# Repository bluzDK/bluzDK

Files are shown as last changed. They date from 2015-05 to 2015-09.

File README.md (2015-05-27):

<p align="center" >
GoGlove
</p>

Bluz DK Hardware Files
==========
Bluz is a Development Kit (DK) that implements the Wiring language and talks to the [Particle](https://www.particle.io/) cloud through Bluetooth Low Energy. It can be accessed through a REST API and programmed from a Web IDE.

These files have been made available online through a [Creative Commons Attribution-ShareAlike 3.0](http://creativecommons.org/licenses/by-sa/3.0/) license.

You are welcome to distribute, remix, and use these files for commercial purposes. If you do so, please attribute the original design to Bluz both on the website and on the physical packaging of the product or in the instruction manual. All derivative works must be published under the same or a similar license.

All items are subject to change over time as the product is designed, so make sure you are always looking at the latest information by pulling often.

##Sections
<b>BOM</b>: Current Bill of Materials for bluz.

<b>Datasheets</b>: Datasheets for all major parts on the board, including the nrf51822 and the MDBT40 module that it uses.

<b>HW Design</b>: Schematics, board layouts, and other design files.

<b>HW Libraries</b>: Eagle CAD libraries for the components used on Bluz DK.

<b>Pin Mapping</b>: Pin mapping diagram for Bluz.

##Tech Specs
<p>Hardware</p>
<ul>
    <li>Nordic Semiconductor nRF51822 SoC</li>
    <li>ARM Cortex M0, 16MHz</li>
    <li>32KB RAM, 256KB FLASH</li>
    <li>Bluetooth LE 4.1</li>
    <li>10 bit ADC</li>
    <li>256KB External FLASH</li>
    <li>3.0V-6V (3.3V compatible)</li>
</ul>
<p>Power Consumption</p>
<ul>
    <li>Connected/Standby: 60uA</li>
    <li>Transmitting Max: 18mA</li>
</ul>
<p>Typical Range (subject to environment):</p>
<ul>
    <li>Indoors: 60-100 feet</li>
    <li>Outdoors: 150-200 feet</li>
</ul>
<p>Software</p>
<ul>
    <li>Spark Web IDE</li>
    <li>Wiring (same as Arduino)</li>
    <li>Native C/C++ Programming</li>
    <li>GCC ARM</li>
    <li>Assembly (if you're that bold)</li>
</ul>
<p>Cloud</p>
<ul>
    <li>Spark Connected</li>
    <li>IFTTT Integrated</li>
    <li>IPv6 Support</li>
    <li>Remote programmable through Spark Cloud</li>
    <li>Control via REST API</li>
</ul>

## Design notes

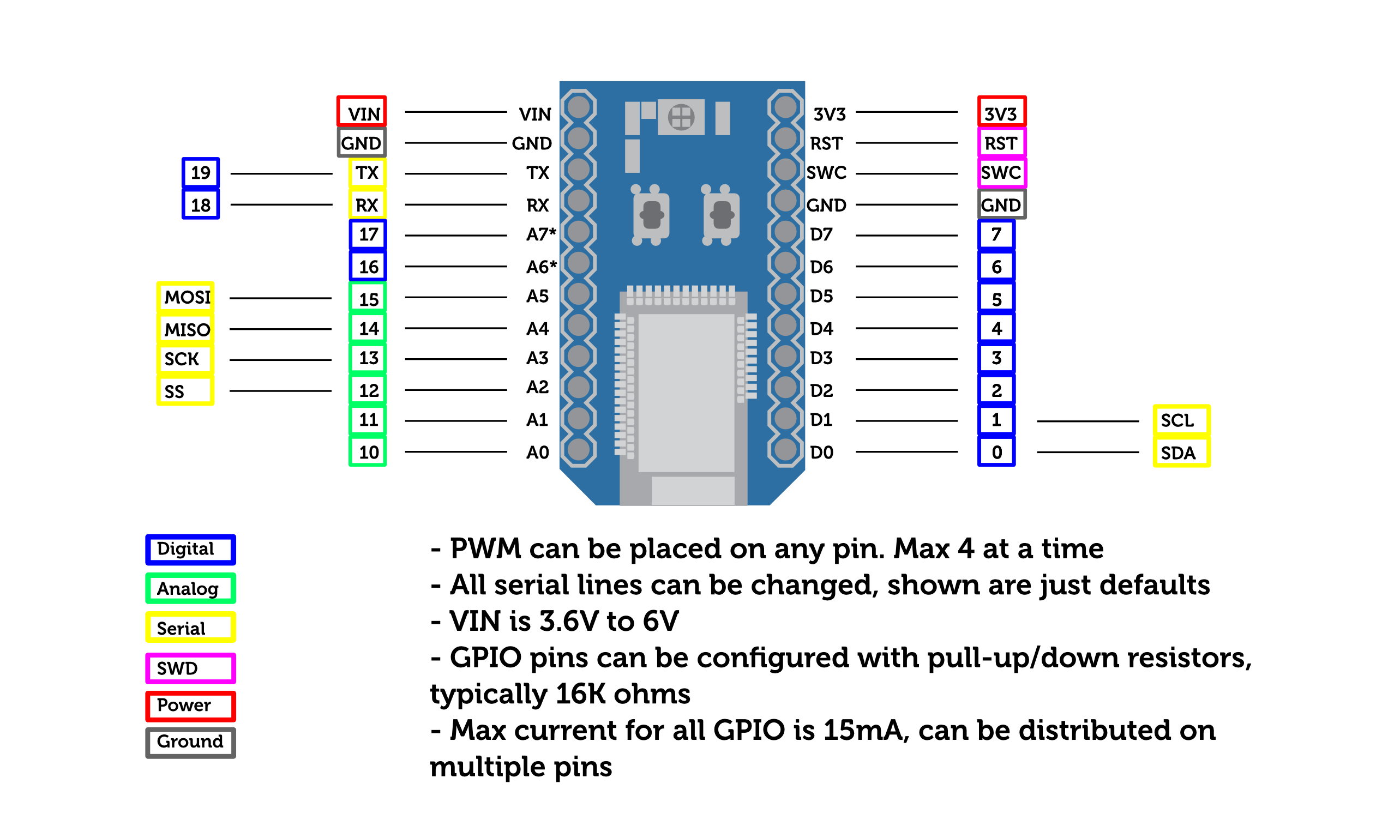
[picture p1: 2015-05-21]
v2/PinMapping/bluz_pinout.png

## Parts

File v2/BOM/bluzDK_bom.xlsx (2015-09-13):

Part(s) | Package | Value | Description | Qty | Manufacturer | Mfg. Part Number | Data Sheet | Notes
U1 | SMD |  | nrf51822 module with 32K RAM | 1 | Raytac | MDBT40-256R | data (http://www.raytac.com/download/MDBT40/MDBT40%20spec-Version%20A2.pdf)
U2 | SOIC-8 | 2Mb | 2Mb SPI Flash | 1 | Microcip | SST25VF020B-80-4I-SAE | data (http://ww1.microchip.com/downloads/en/DeviceDoc/20005054C.pdf)
U3 | SOT-23-3 |  | Linear regulator with 3.3V output, 3.7V-6.0V Input | 1 | Microchip | MCP1700T-3302E/TT | data (http://ww1.microchip.com/downloads/en/DeviceDoc/20001826C.pdf)
Q1 |  | 32.768KHz | 20ppm, 9pF, 32.768KHz crystal | 1 |  | ABS06-32.768KHZ-9-T | data (http://www.abracon.com/Resonators/ABS06.pdf)
C1-C3 | 0603 | 1uF | 0603 Package | 1 |  | CL10B105KP8NNNC | data (http://www.samsungsem.com/kr/front/downloadcms.do?fileName=S_CL10B105KP8NNNC.pdf)
C4, C5 | 0603 | 0.1uF | 0603 Package | 3 |  | GRM188R71C104KA01D | data (http://search.murata.co.jp/Ceramy/image/img/A01X/partnumbering_e_01.pdf)
C6, C7 | 0603 | 12pF | 0603 Package | 2 |  | CL10C120JB8NNNC | data (http://www.samsungsem.com/kr/front/downloadcms.do?fileName=S_CL10C120JB8NNNC.pdf)
R1-R3 | 0603 | 4.7k Ohm | 4.7k Ohm | 3 |  | CRCW06034K70JNEA | data (http://www.vishay.com/docs/20035/dcrcwe3.pdf)
R4-R5 | 0603 | 1k Ohm | 1k Ohm | 2 |  | CRCW06031K00FKEA | data (http://www.vishay.com/docs/20035/dcrcwe3.pdf)
R6 | 0603 | 10k Ohm | 10k Ohm | 1 |  | CRCW060310K0FKEA | data (http://www.vishay.com/docs/20035/dcrcwe3.pdf)
S1, S1 | SMD |  | 3.5mmx2.9mm Tactile Switch | 2 |  | EVP-AA202K | data (http://industrial.panasonic.com/www-data/pdf/ATK0000/ATK0000CE26.pdf)
L1 | SMD |  | 3.2mm x 2.7m RGB LED | 1 |  | CLVBA-FKA-CAEDH8BBB7A363 | data (http://www.cree.com/~/media/Files/Cree/LED%20Components%20and%20Modules/HB/Data%20Sheets/CLVBAFKA.pdf)
L2 | 0603 |  | White SMD LED | 1 |  | LW Q38G-Q1S1-3K6L-1 | data (http://www.osram-os.com/Graphics/XPic6/00086183_0.pdf)
JP1, JP2 | Thru |  | 0.1" 12-pin header | 2 |  | 68000-412HLF | data (http://www.digikey.com/product-detail/en/68000-412HLF/609-3266-ND/1878525)

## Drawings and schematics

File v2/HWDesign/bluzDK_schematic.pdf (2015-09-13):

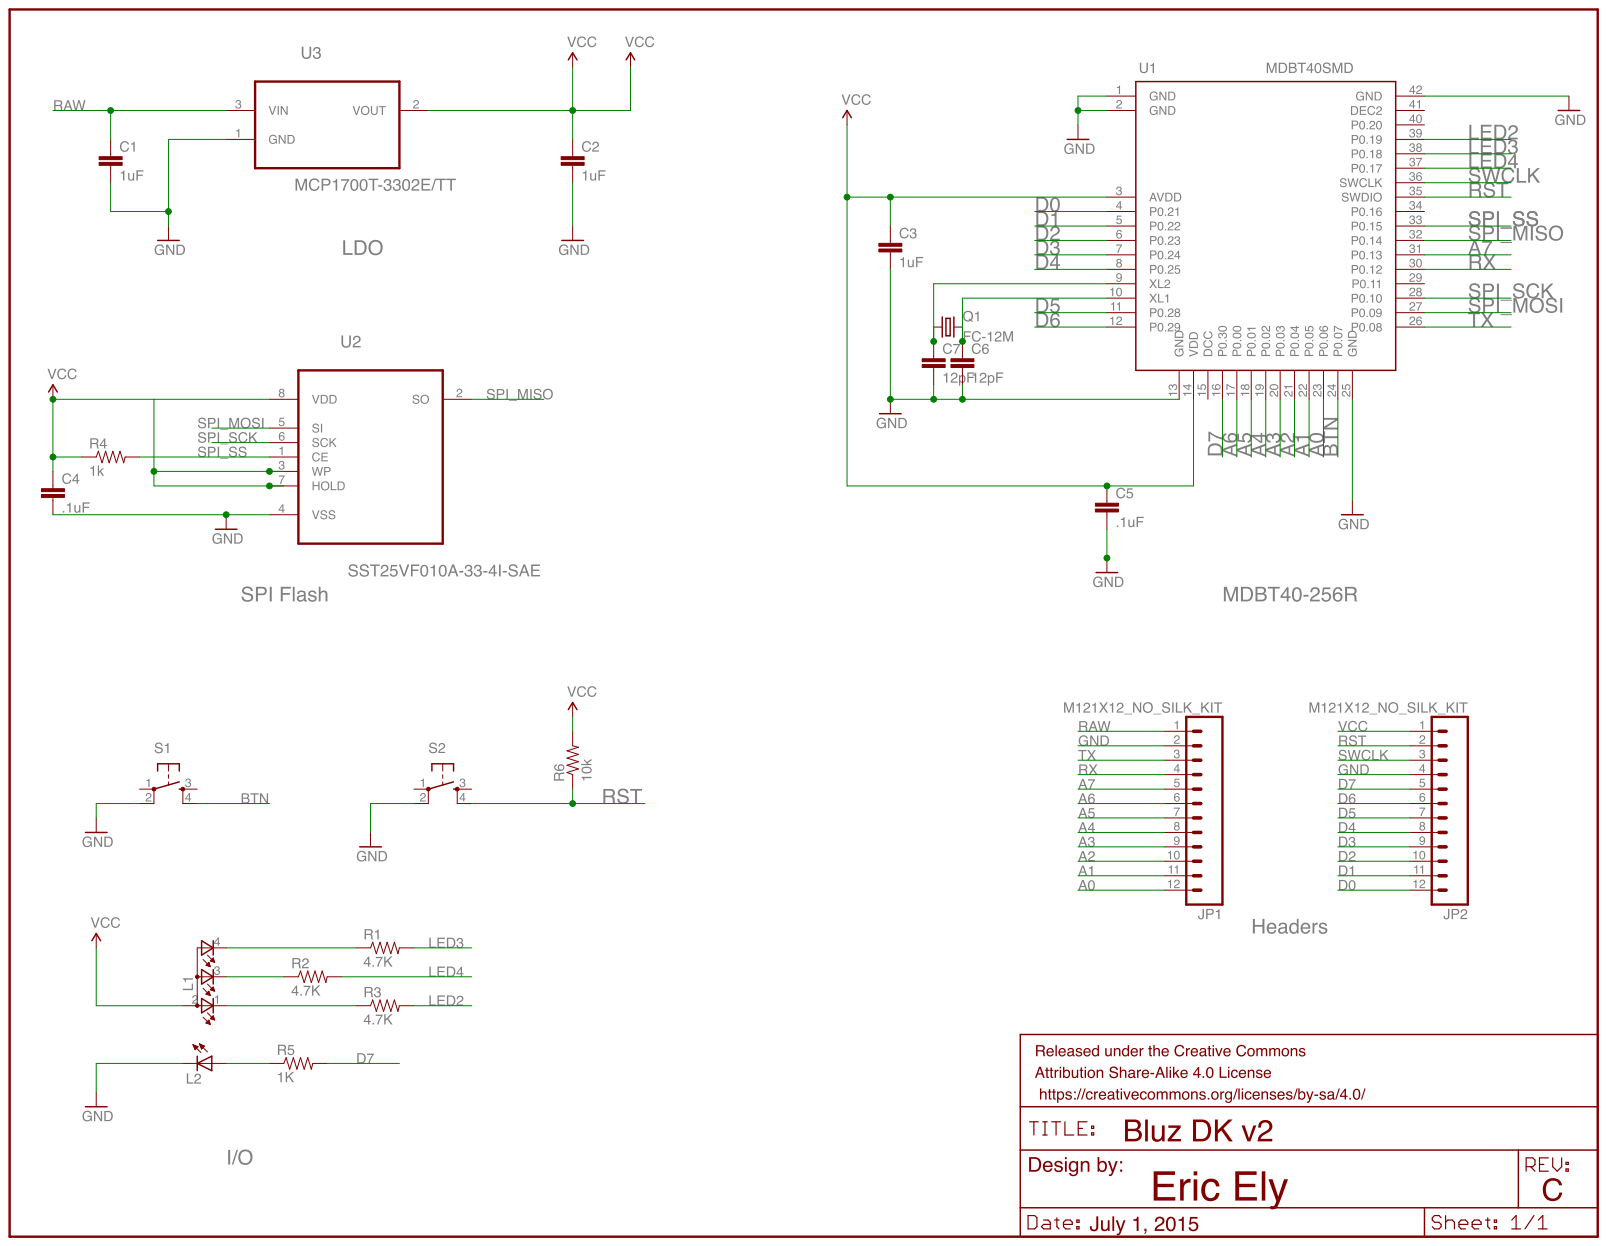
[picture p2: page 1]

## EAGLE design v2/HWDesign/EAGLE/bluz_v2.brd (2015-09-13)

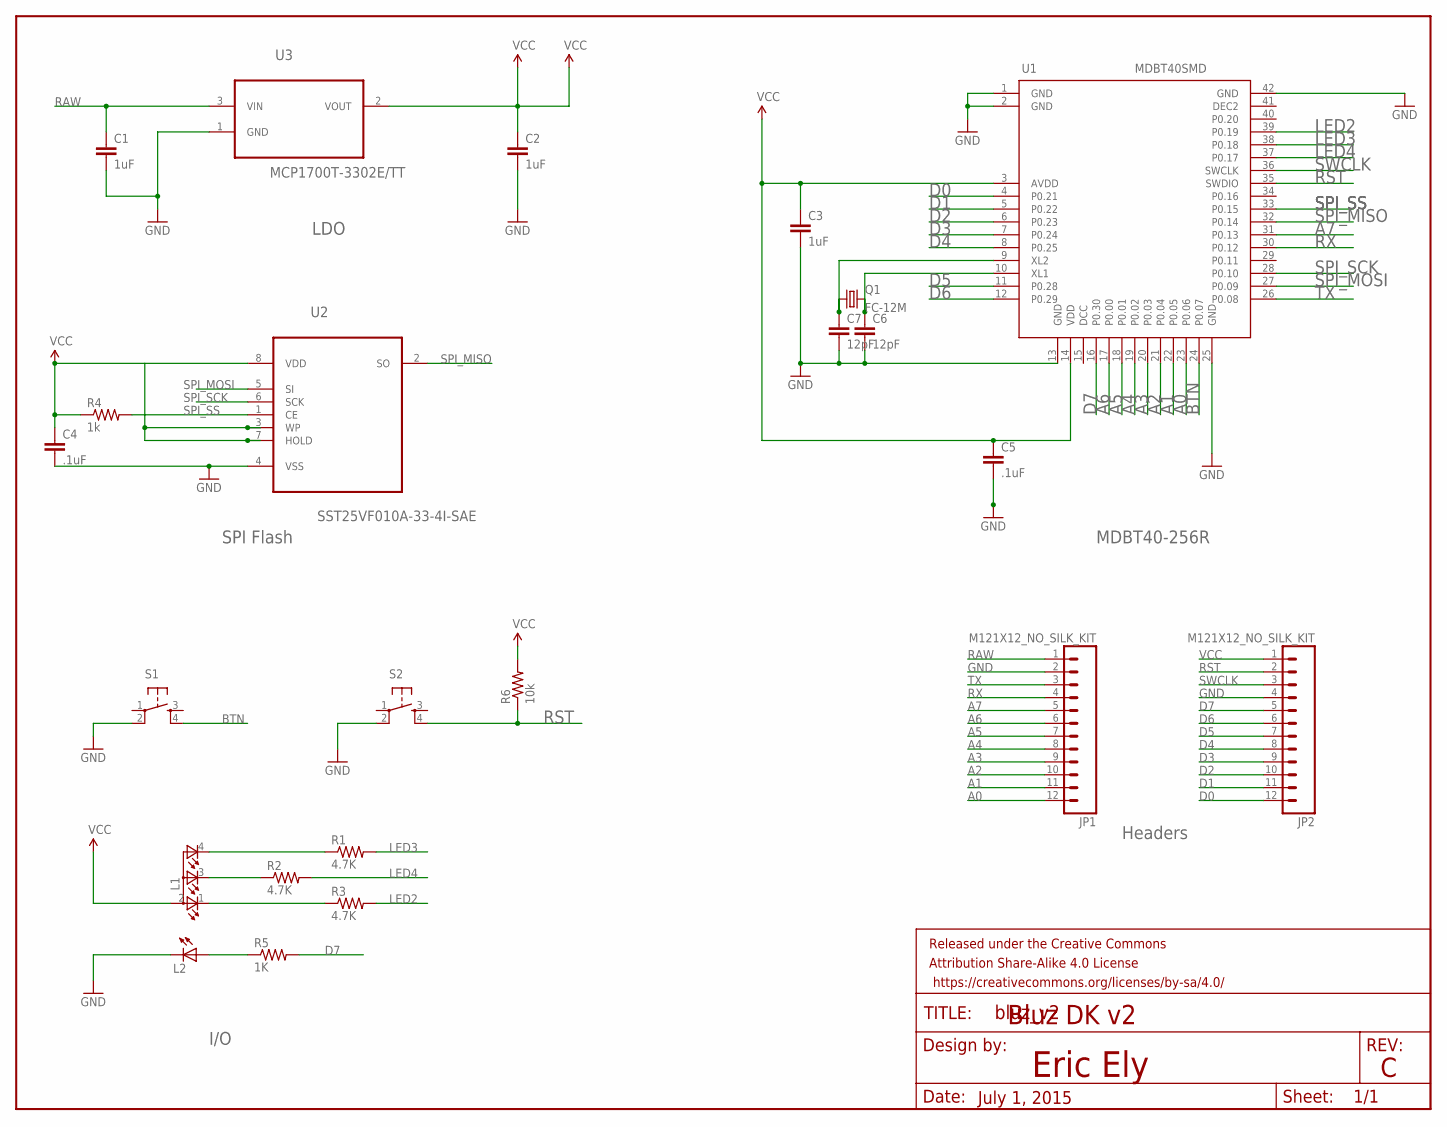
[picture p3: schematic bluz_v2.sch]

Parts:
C1, C2, C3: 1uF; 0603-CAP
C4, C5: .1uF; 0603-CAP
C6, C7: 12pF; 0603-CAP
FRAME1: FRAME-LETTER; CREATIVE_COMMONS
JP1, JP2: M121X12_NO_SILK_KIT; 1X12_NO_SILK_KIT
L1: TOPLED-3PLCC; P-LCC-4-3
L2: LEDCHIP-LED0603; CHIP-LED0603
Q1: FC-12M
R1, R2, R3: 4.7K; 0603-RES
R4: 1k; 0603-RES
R5: 1K; 0603-RES
R6: 10k; 0603-RES
S1, S2: TAC_SWITCHSMD; TACTILE_SWITCH_SMD
U1: MDBT40SMD; MDBT40
U2: SST25VF010A-33-4I-SAE; SOIC127P600X175-8N
U3: MCP1700T-3302E/TT; SOT95P237X112-3N

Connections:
A0: JP1.12, U1.23 (P0.06)
A1: JP1.11, U1.22 (P0.05)
A2: JP1.10, U1.21 (P0.04)
A3: JP1.9, U1.20 (P0.03)
A4: JP1.8, U1.19 (P0.02)
A5: JP1.7, U1.18 (P0.01)
A6: JP1.6, U1.17 (P0.00)
A7: JP1.5, U1.31 (P0.13)
BTN: S1.4, U1.24 (P0.07)
D0: JP2.12, U1.4 (P0.21)
D1: JP2.11, U1.5 (P0.22)
D2: JP2.10, U1.6 (P0.23)
D3: JP2.9, U1.7 (P0.24)
D4: JP2.8, U1.8 (P0.25)
D5: JP2.7, U1.11 (P0.28)
D6: JP2.6, U1.12 (P0.29)
D7: JP2.5, R5.2, U1.16 (P0.30)
GND: C1.2, C2.2, C3.2, C4.2, C5.2, C6.2, C7.2, JP1.2, JP2.4, L2.C, S1.2, S2.2, U1.1 (GND), U1.2 (GND), U1.13 (GND), U1.25 (GND), U1.42 (GND), U2.4 (VSS), U3.1 (GND)
LED2: R3.2, U1.39 (P0.19)
LED3: R1.2, U1.38 (P0.18)
LED4: R2.2, U1.37 (P0.17)
unnamed: C7.1, Q1.1, U1.9 (XL2)
unnamed: C6.1, Q1.2, U1.10 (XL1)
unnamed: L2.A, R5.1
unnamed: L1.1 (CRED), R3.1
unnamed: L1.3 (CBLUE), R2.1
unnamed: L1.4 (CGREEN), R1.1
RAW: C1.1, JP1.1, U3.3 (VIN)
RST: JP2.2, R6.1, S2.4, U1.35 (SWDIO)
RX: JP1.4, U1.30 (P0.12)
SPI_MISO: U1.32 (P0.14), U2.2 (SO)
SPI_MOSI: U1.27 (P0.09), U2.5 (SI)
SPI_SCK: U1.28 (P0.10), U2.6 (SCK)
SPI_SS: R4.2, U1.33 (P0.15), U2.1 (CE)
SWCLK: JP2.3, U1.36 (SWCLK)
TX: JP1.3, U1.26 (P0.08)
VCC: C2.1, C3.1, C4.1, C5.1, JP2.1, L1.2 (A2), R4.1, R6.2, U1.3 (AVDD), U1.14 (VDD), U2.3 (WP), U2.7 (HOLD), U2.8 (VDD), U3.2 (VOUT)

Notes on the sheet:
LDO
SPI Flash
I/O
Headers
MDBT40-256R
Eric Ely
Bluz DK v2
July 1, 2015

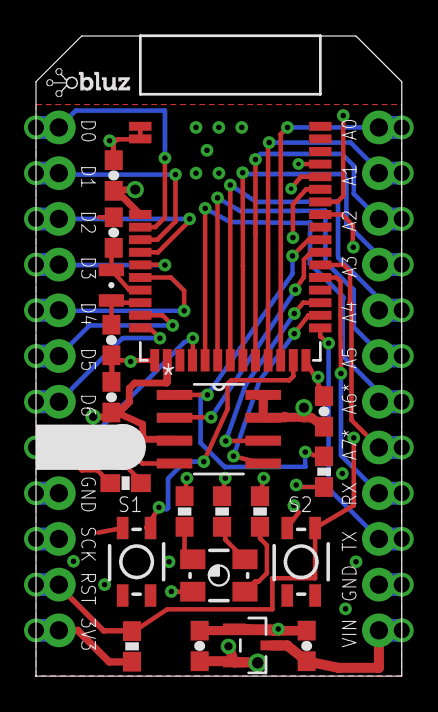
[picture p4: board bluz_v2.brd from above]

Board: 2 copper layers, 20.3 x 35.6 mm, 26 parts (1 on the bottom side), 37 nets.

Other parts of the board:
U$1: BLUZE_LOGO_LOW_RES
U$2: MAKE_X2

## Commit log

2015-05-21 first schematic
2015-05-21 Added BOM
    [bluzDK_bom.xlsx]
2015-05-27 updated datasheet of SPI flash to the correct one, had an older version in there
2015-07-01 fix a few issues with capacitor values and placement
2015-07-02 updated schematic after routing. eagle cad files after first pass in routing
    [bluz_v2.brd, bluz_v2.sch]
2015-07-02 cleaned up some issues. filled remaining top layer with ground
    [bluz_v2.brd]
2015-07-03 change part number for LDO in BOM. update PCB. script for generating gerbers
    [bluzDK_bom.xlsx, bluz_v2.brd]
2015-07-06 fix an issue on the PCB
    [bluz_v2.brd, bluz_v2.sch]
2015-07-06 update SPI FLash part on BOM
    [bluzDK_bom.xlsx]
2015-08-19 larger silkscreen. remove labels. copper on bottom of castellated edges. move buttons further in
    [bluz_v2.brd, bluz_v2.sch]
2015-09-01 updated RGB LED to new part. changed resistors for new LED. updated labeling on bluz.
    [bluzDK_bom.xlsx, bluz_v2.brd, bluz_v2.sch]
2015-09-13 updated BOM with correct RGB LED
    [bluzDK_bom.xlsx]
2015-09-13 cleanup some naming mistakes. properly labeled all capacitors
    [bluzDK_bom.xlsx, bluz_v2.brd, bluz_v2.sch]
2015-10-06 programmer script to program and provision a new bluz PCB for the cloud

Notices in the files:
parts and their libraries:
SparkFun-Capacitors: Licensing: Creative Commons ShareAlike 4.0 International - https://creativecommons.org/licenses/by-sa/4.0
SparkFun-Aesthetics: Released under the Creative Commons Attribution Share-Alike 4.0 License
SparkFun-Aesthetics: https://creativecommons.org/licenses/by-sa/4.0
